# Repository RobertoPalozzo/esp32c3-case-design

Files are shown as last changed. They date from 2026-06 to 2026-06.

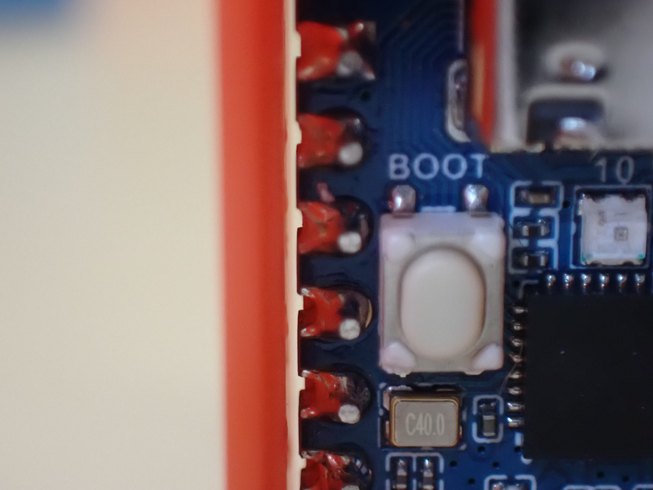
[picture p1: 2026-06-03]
images/gap_l_side.jpg

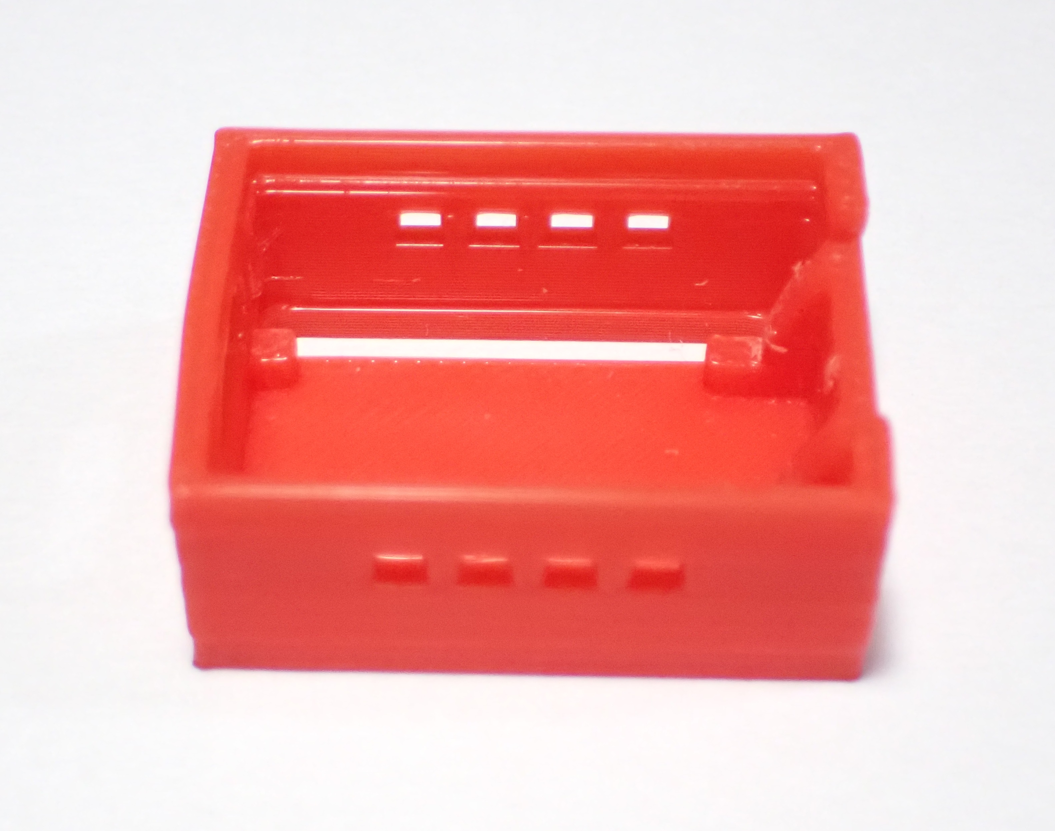
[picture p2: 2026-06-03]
images/internal1.jpg

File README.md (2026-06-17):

# ESP32C3 Case Design

A documentation website for the design and 3D printing journey of a protective case for the ESP32-C3 Zero microcontroller board.

## Project Overview

This project was completed as part of **Assessment Task 3** for the **Certificate III in Information Technology** at **Kangan Institute – Broadmeadows VIC**.

The website documents the full design process, from the first prototype to the final product, including problems encountered, improvements made, and test results.

## Website Pages

| Page | Description |
|---|---|
| `index.html` | Home page – project introduction and purpose |
| `prototype1.html` | Prototype 1 – first design, photos, pros, cons and planned improvements |
| `prototype2.html` | Prototype 2 – 3D design images, improvements from Prototype 1 |
| `final.html` | Final Design – features, comparison table across all prototypes |
| `contact.html` | Contact – author info and feedback form |

## Technology Used

- HTML5 / CSS3
- Google Fonts (Inter)
- 3D modelling: Tinkercad
- 3D printer: BambuLab A1 (PLA filament)
- IDE: Visual Studio Code
- Version control: Git / GitHub

## Live Website

[View on GitHub Pages](https://robertopalozzo.github.io/esp32c3-case-design/)

## Repository Structure

```
esp32c3-case-design/
├── index.html
├── prototype1.html
├── prototype2.html
├── final.html
├── contact.html
├── style.css
├── robots.txt
├── sitemap.xml
│
├── css/
│   └── style.css
│
└── images/
    ├── ESP32 C3 Zero.jpg
    ├── Prot_1_1.JPG ... Prot_1_8.JPG
    └── Design_2_1.png ... Design_2_7.png
```

## Author

**Roberto Palozzo**

## Student ID

**200096469**

Certificate III in Information Technology  
Kangan Institute – Broadmeadows VIC – 2026

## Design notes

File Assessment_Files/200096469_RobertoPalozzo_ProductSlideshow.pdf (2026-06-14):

# ESP32-C3 Zero Protective Case

Product Slideshow | Roberto Palozzo | 200096469

Product Overview

Product name: ESP32C3 Zero Protective Case Purpose: Protect the ESP32-C3 Zero board during classroom use, maintaining access to USB-C, GPIO pins, and buttons.
Problem solved: Boards are frequently handled and are at risk of short circuits, bent pins, and breakage from drops. The case protects the board while still leaving the USB-C port, GPIO pins, and BOOT/RST buttons accessible. Ventilation is provided by holes on both sides and the lid (No. 10 square holes 4mm² in two rows on each side and No. 5 square holes 4mm² on the lid). Model created in Tinkercad. Printed in PLA with a BambuLab A1 printer. The product was developed in three prototyping phases, with testing and improvements at each iteration.
Intended users: Students, makers, and engineers who use microcontrollers in the classroom or lab.

Insert image here
(3D model or printed prototype)

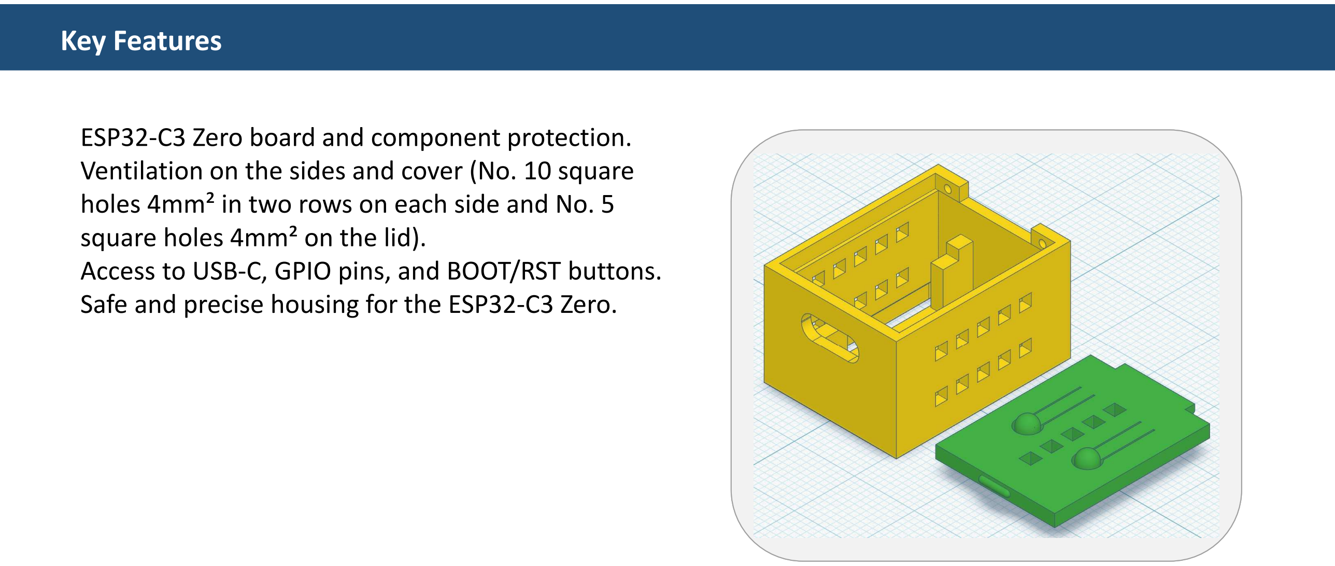
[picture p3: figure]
Key Features; square holes 4mm² on the lid).; Insert image here (3D model or printed prototype)

ESP32-C3 Zero board and component protection. Ventilation on the sides and cover (No. 10 square holes 4mm² in two rows on each side and No. 5

Access to USB-C, GPIO pins, and BOOT/RST buttons. Safe and precise housing for the ESP32-C3 Zero.

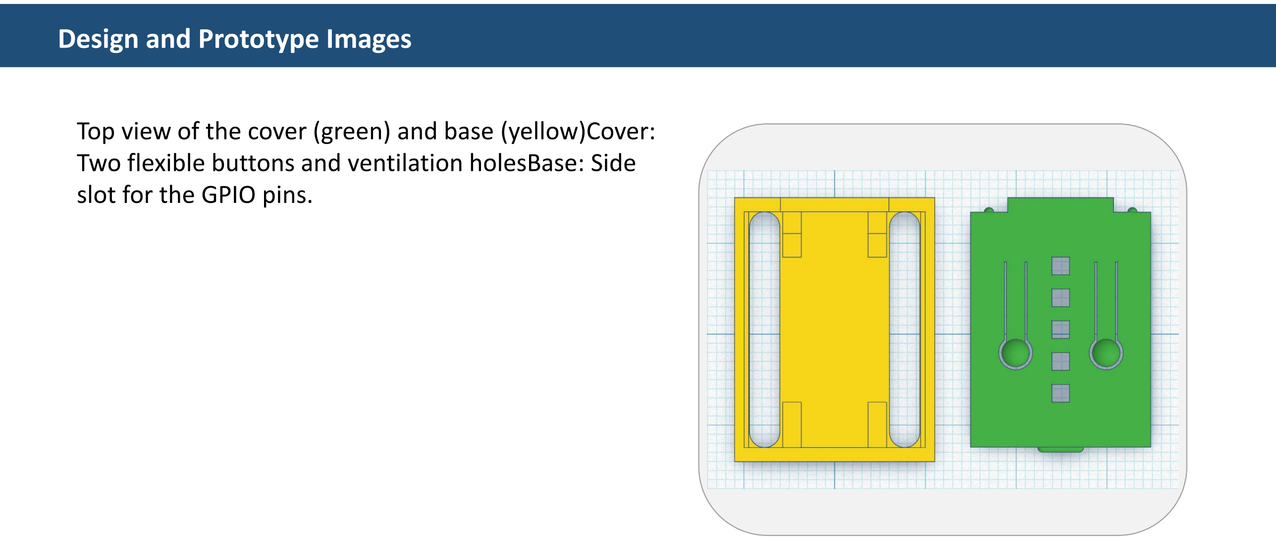
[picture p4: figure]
Design and Prototype Images; slot for the GPIO pins.; Insert image here (3D model or printed prototype)

Top view of the cover (green) and base (yellow)Cover: Two flexible buttons and ventilation holesBase: Side

Testing and Improvements

Tested: Insertion of the ESP32-C3 Zero board, access to USB-C, pins and buttons, ventilation, robustness, and print quality. Prototype 1 issues: Internal supports too large (card won't fit); pins protruding from the bottom; cover too narrow (warped wall); button pins too long (buttons getting stuck); insufficient ventilation. Modifications (Prototype 2): Supports widened to accommodate the board; bottom deepened to protect the pins; cover refined; button pins shortened; more ventilation holes on the sides. Remaining issues: Pins still close to the bottom, slots not centered, ventilation needs to be centered, cover still a bit tight. Final design: Centered slots; raised bottom (pins 0.1 mm from the surface); more ventilation holes on the covers and centered (the lowest ones on the sides lowered by 1 mm to fit under the board); optimized cover tolerance.

Insert image here
(3D model or printed prototype)

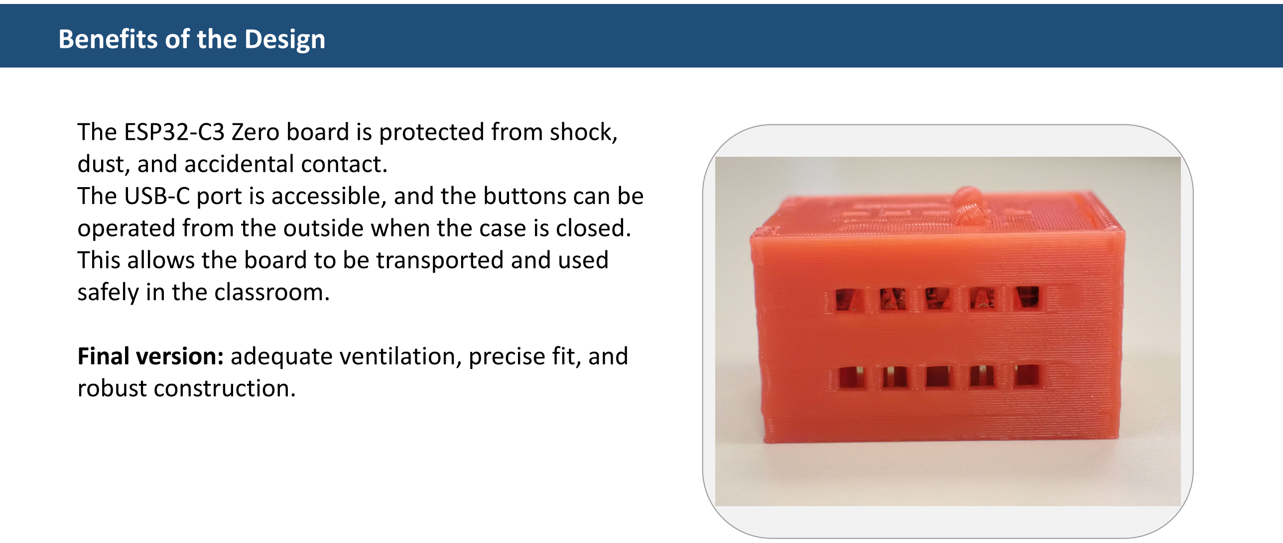
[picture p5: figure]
Benefits of the Design; dust, and accidental contact.; safely in the classroom.; robust construction.

The ESP32-C3 Zero board is protected from shock,

The USB-C port is accessible, and the buttons can be operated from the outside when the case is closed. This allows the board to be transported and used

Final version: adequate ventilation, precise fit, and

Final Reflection

What worked well: The iterative process allowed me to correct every problem; the flexible buttons are an effective solution.

What I would change: Center the ventilation holes and slots sooner, and test the lid fit and tolerance earlier.

What I learned: The importance of measuring accurately, testing real prototypes, and using feedback to improve the design.

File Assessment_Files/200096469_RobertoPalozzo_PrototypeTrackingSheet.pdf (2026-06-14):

OFFICIAL#_x000d_

Student name: | Roberto Palozzo Student number: | 200096469 Project/team:

ESP32-C3 Zero
Case - Team
Palozzo
Prototype Number | Date | Print Time (hours) | Material Use (g) | Estimated Cost ($) | Test Result | Comments / Issues / Improvements
Prototype 1 | 30/05/2026 | 0.42 | 4.68 | $0.09 | Fail

The circuit board supports are too tight. The board won't fit. The pins are protruding from the case, risking damage from a fall or a short circuit when touching a conductive surface. The cover is slightly narrow, one wall remains slightly deformed after insertion. The button pins on the cover are too long, the buttons remain stuck.

Prototype 2 | 01/06/2026 | 0.48 | 5.42 | $0.11

Needs
Improvement

The circuit board location has been modified to allow for easier insertion into the case. The case depth has been increased to protect the pins from damage in the event of a fall. The cover has been modified for greater precision in the housing. The button pins have been shortened.

Final | 06/06/2026 | 0.54 | 6.11 | $0.12 | Pass

Pin-centered slots. Increased the bottom height to raise the board pins by 0.1 mm from the contact surface. Increased the number of ventilation holes and centered them. The lowest-level holes have been lowered by 1 mm so they remain below the circuit board.

Summary
Total print time (hours) | 1.44
Total material use (g) | 16.21
Total estimated cost ($) | $0.32

Instructions
1. Enter each prototype version or final product in the table above.
2. Use the Test Result dropdown to record Pass, Fail, Needs Improvement or Retest.
3. Check that formulas calculate total print time, material use and cost before exporting to PDF.

### ESP32-C3 Zero Protective Case - Prototype Tracking Sheet

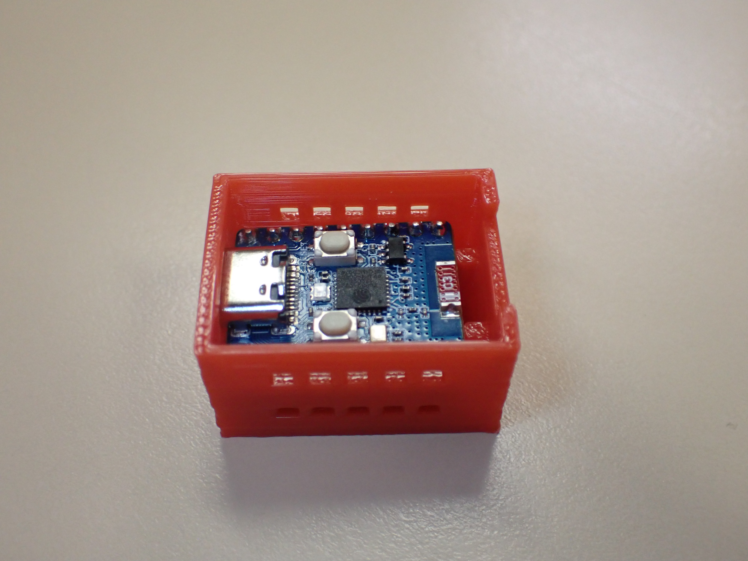
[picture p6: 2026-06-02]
images/board3.jpg

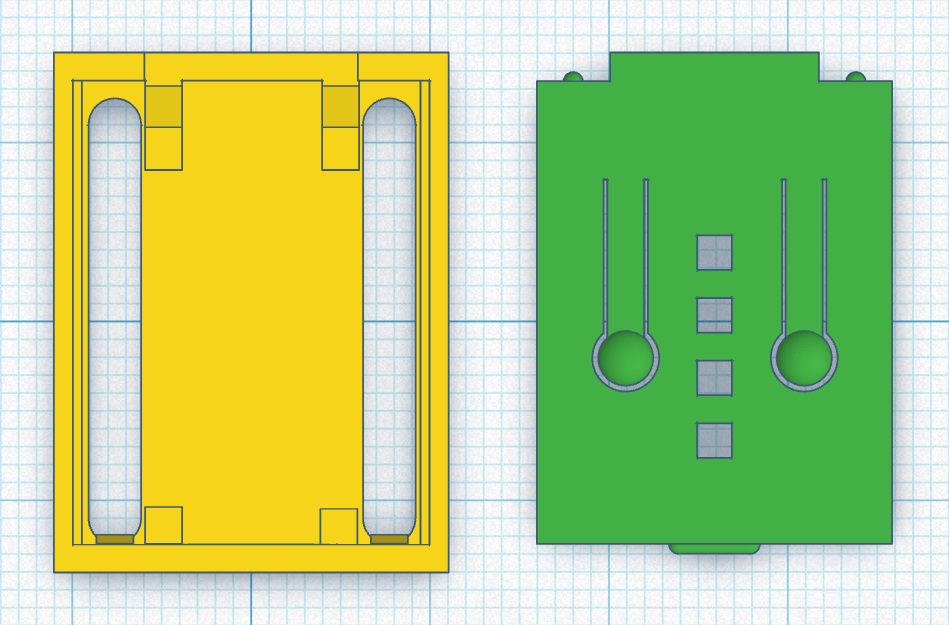
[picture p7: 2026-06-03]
images/prot1up.jpg

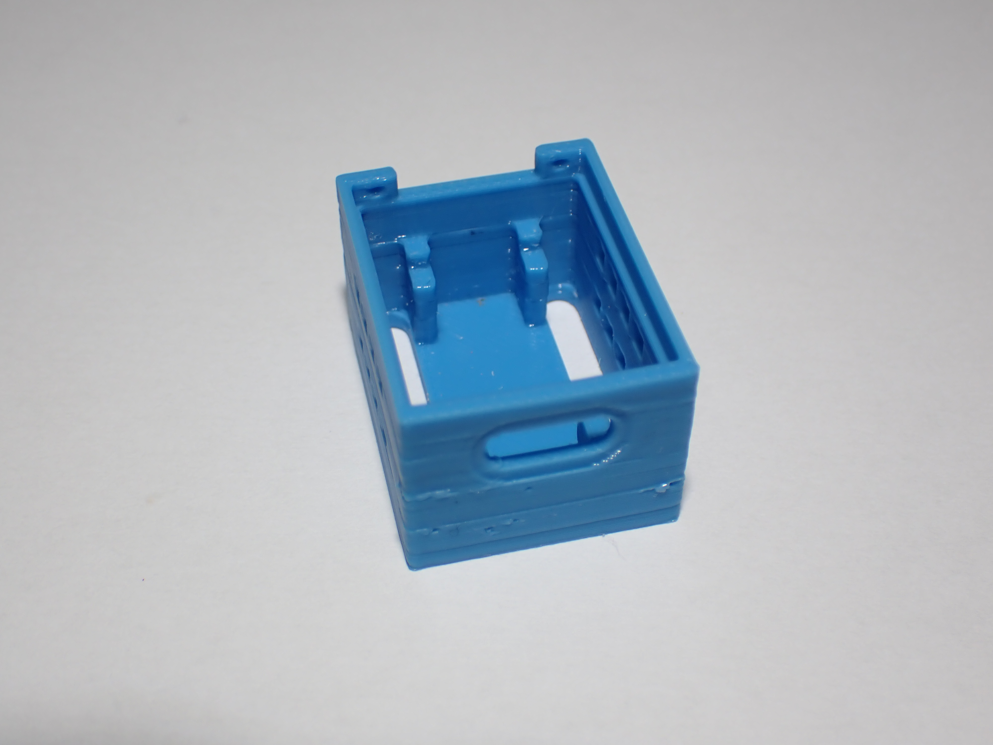
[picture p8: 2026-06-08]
images/internal2.jpg

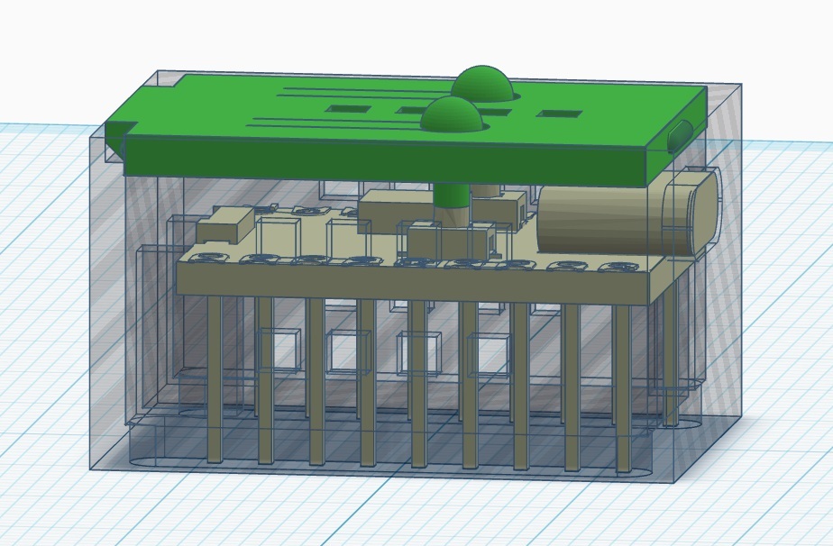
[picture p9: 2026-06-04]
images/prot2side1.jpg

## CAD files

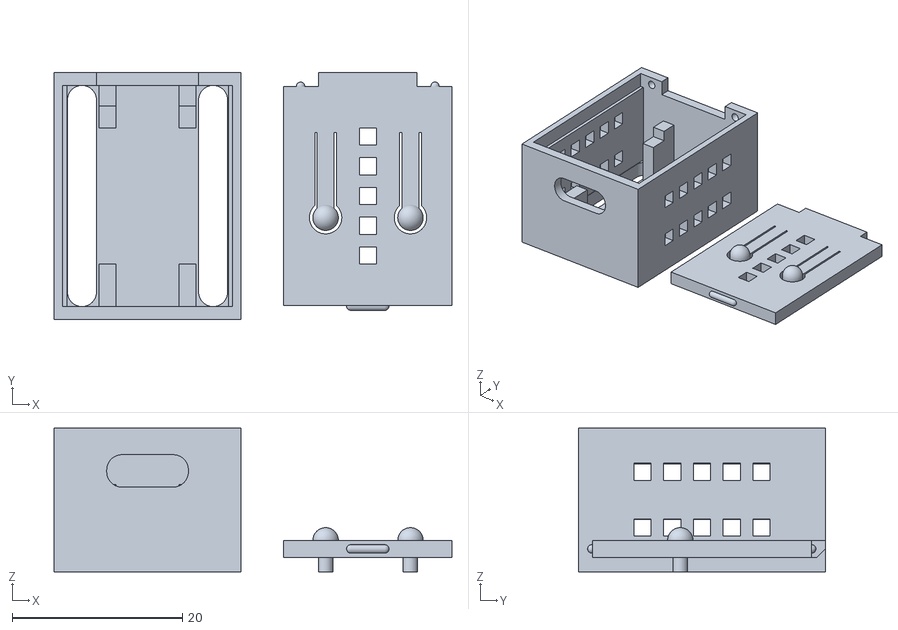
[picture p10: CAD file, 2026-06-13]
Assessment_Files/200096469_RobertoPalozzo_Final_Design.stl
46.8 x 29.0 x 16.9

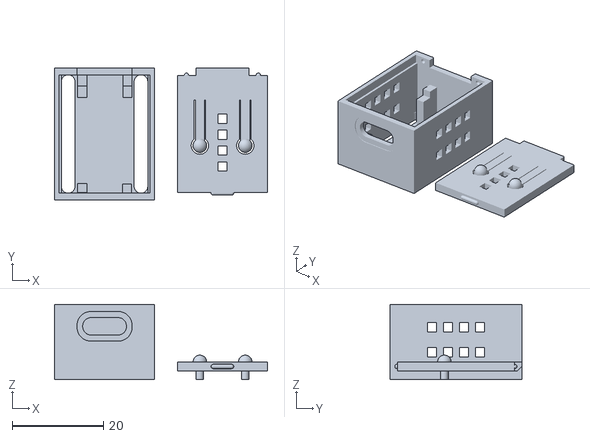
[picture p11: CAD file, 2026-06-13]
Assessment_Files/200096469_RobertoPalozzo_Prototype_2.stl
46.8 x 29.0 x 16.5

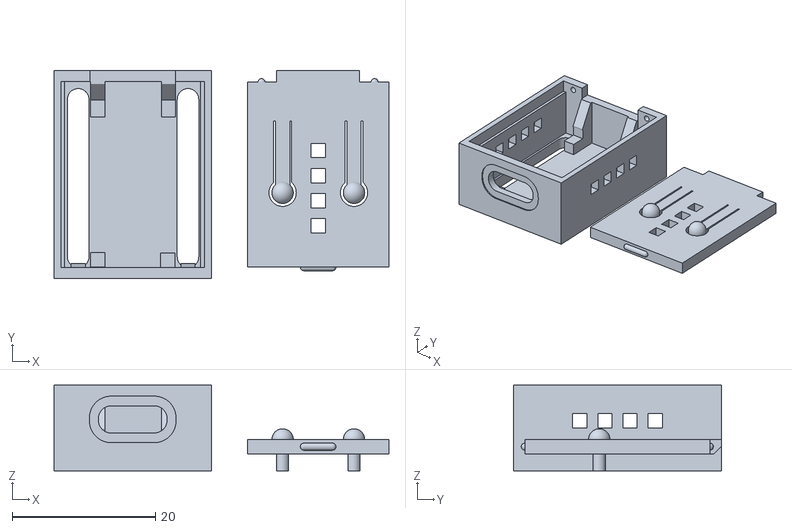
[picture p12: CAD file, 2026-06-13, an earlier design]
Assessment_Files/200096469_RobertoPalozzo_Prototype_1.stl
46.8 x 29.0 x 12.0

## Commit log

2026-05-29 Add all pages, images and styles for ESP32C3 case design website
    - Complete all HTML pages: index, prototype1, prototype2, final, contact
    - Add professional color scheme and layout in style.css
    - Add 8 prototype 1 photos and 7 prototype 2 design images
    - Add feedback form, comparison table, pros/cons sections
    - Add nav-brand link to Home on all pages
2026-06-03 Modificato la foto della home page e apportate alcune modifiche alla pagina del primo prototipo.
2026-06-04 Modificata la foto del case 1
2026-06-08 Update image alt text in prototype2.html
2026-06-08 Update image alt texts for Prototype 1
2026-06-08 Update image alt text for prototype photos
